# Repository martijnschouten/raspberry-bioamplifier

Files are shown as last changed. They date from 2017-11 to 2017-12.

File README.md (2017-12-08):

# Raspberry-bioamplifier
This repository contains the source of a bioamplifier based on a Raspberry Pi Zero w that streams data to matlab. The project was made at the NIFTy group at the University of Twente as a demonstrator for the IEEE student measurement challange at the IEEE conference in Glasgow in 2017. 

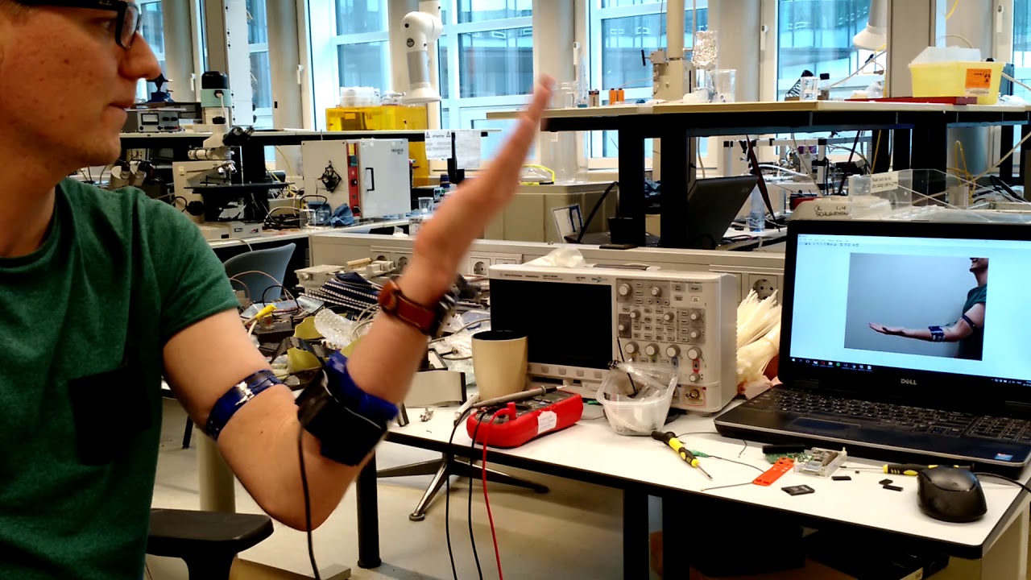
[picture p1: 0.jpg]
Link to Youtube video (https://youtu.be/Y4tf-qSCpeE "Video on Youtube")


(Click image to play video)

To be able to measure the EMG and FMG a bioamplifier shield for the raspberry pi zero w is develloped. The schematic and the layout of the pcb can be found in the bioamplifier folder. This PCB contains an 24 bit ADC, a quad opamp for measurements and one aditional single opamp that can be used as a driven right leg. As this was a prototype, each opamp has many resistors placed around it that do not all have to be soldered. By soldering certain resistors the opamp can be configured as a FMG sensor or as an EMG sensor. The specific configuration used for the demo in Glasgow can be found in the folder "demo configuration"

The data form the adc is read out using an Raspberry Pi Zero W. The program written in c++ used to read out the ADC and send the data to matlab via TCP/IP can be found in the "raspberry code" folder. The matlab scripts used to stream and process the data on the other side can be found in the folder "matlab scripts".

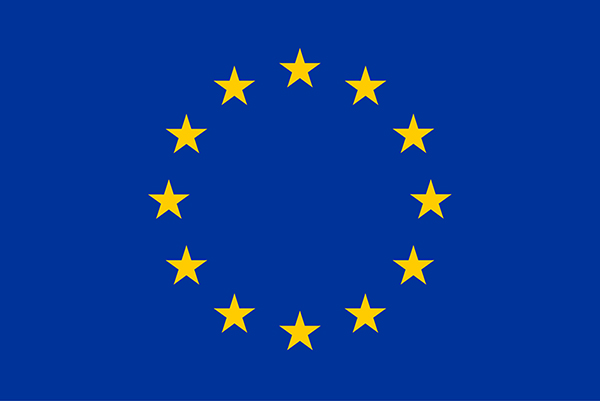
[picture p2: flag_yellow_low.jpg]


This project has received funding from the European Union’s Horizon 2020 research and innovation programme under grant agreement No. 688857 (SoftPro)

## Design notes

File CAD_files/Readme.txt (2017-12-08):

More info about cad files on: https://www.thingiverse.com/thing:2699263
The prints are made on a FlashForge Creator Pro fitted with a Flexion Extruder. The material used is NinjaFlex for the non conductive parts and PI-ETPU 85-700+ (http://palmiga.com) for the conducive parts. 

Band_ETPU.stl and Band_NinjaFlex.stl are one model, the .stl files have the same coordinate axis and can easily be combined in sliver software like simplfy3D, then assign each .stl to one material. BandCapEtpu.stl and BandCapNinjaFlex.stl are also one model.

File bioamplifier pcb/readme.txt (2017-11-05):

The PCB is designed using Kicad and it's dimensions are such that it can be ordered as a 5x5cm pcb at the big chinese PCB manufacturers.

The PCB contains an 24 bit ADC, a quad opamp for measurements and one aditional single opamp that can be used as a driven right leg. As this was a prototype, each opamp has many resistors placed around it that do not all have to be soldered. By soldering certain resistors the opamp can be configured as for example a FMG sensor or as an EMG sensor.

Bugs and options for improvement:
1. The capacitances (C6-C9) of the low pass filters in front of the ADC result in noise on the analog ground, when high capacitance values are used (1 uF).
2. Daisy chaining the boards is not possible since:
	-No external clock can supplied
	-A mix up of the CS and the DRDY signal...
3. The u.fl connectors are not very reliable, it might be a good idea to replace them mmcx connectors or a 3d printed connector
4. The resolution of the ADC is not fully used due to the large amount of noise. Further research on what is causing this noise is necessary.

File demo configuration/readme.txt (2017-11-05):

FMG:
U1C (channel 3) is configured as an transimpedance amplifier to the analog ground with an feedback resistor of 3.9 kOhm. The shielding of the u.fl connector is not used since there was a short from the shield to the core near the FMG sensor. 

U1B (channel 2) is not used, but is configured as a unity gain amplifier for debug purposes. It's u.fl connector is used to connect the general ground to FMG resistor. The general ground is 1.8 volt below the analog ground and therefore can be used to apply a voltage over the FMG resistor.

EMG:
U1A (channel 1) is used as reference channel. The measured signal is send back to the patient with a negative gain via the driven right leg. This results in feedback loop pulling this signal to zero.

U1D (channel 4) is used as a measurement channel. This amplifier contains a high pass filter in order to filter out the DC offset of the signal and therefore allow a larger gain.

Futhermore the signal and in case of channel 4 the AC part of the signal is fed back to the shield. This is done in order to reduce the input capacitance due to the capacitance of the shielded cable.

U5 is configured as an amplifier with negative feedback, such that it functions as a driven right leg. The gain of the negative amplifier is limited at high frequencies (cutoff at 16Hz).

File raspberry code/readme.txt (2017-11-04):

In order to run and compile the code:

1. copy the content of this folder to /usr/local/bin

2. give readSPI and readSPIhack the correct rights:
sudo chmod 775 /usr/local/bin/readSPI
sudo chmod 775 /usr/local/bin/readSPIhack

3. install the boost libraries
sudo apt-get install libboost-all-dev

4. install wiring pi:
sudo apt-get install wiringpi

5. enable SPI under interfacing options in the config menu accessed using:
sudo raspi-config

To make the program starts at startup add:
/bin/bash /usr/local/bin/readSPIhack.sh
to /etc/rc.local, just above the exit 0 command

To recompile use the compile.sh script
bash /usr/local/bin/compile.sh

To recompile the preheader use the compileStdafx.sh script
bash /usr/local/bin/compileStdafx.sh

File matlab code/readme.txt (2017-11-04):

The demo script contains a script that displays different pictures based on the measured EMG and FMG signal

The streamAndPlotData script can be used for debugging, it shows the signal of all channels.

The class ADS131a04 can be used to set up a connection with the raspberry.

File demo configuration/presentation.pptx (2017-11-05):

## IEEE sensors – student contest

Wifi bio AMPLifier

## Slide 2

- Voltage source
- Transimpedance amplifier
- That’s it

- Resistance measurements

- Schematic

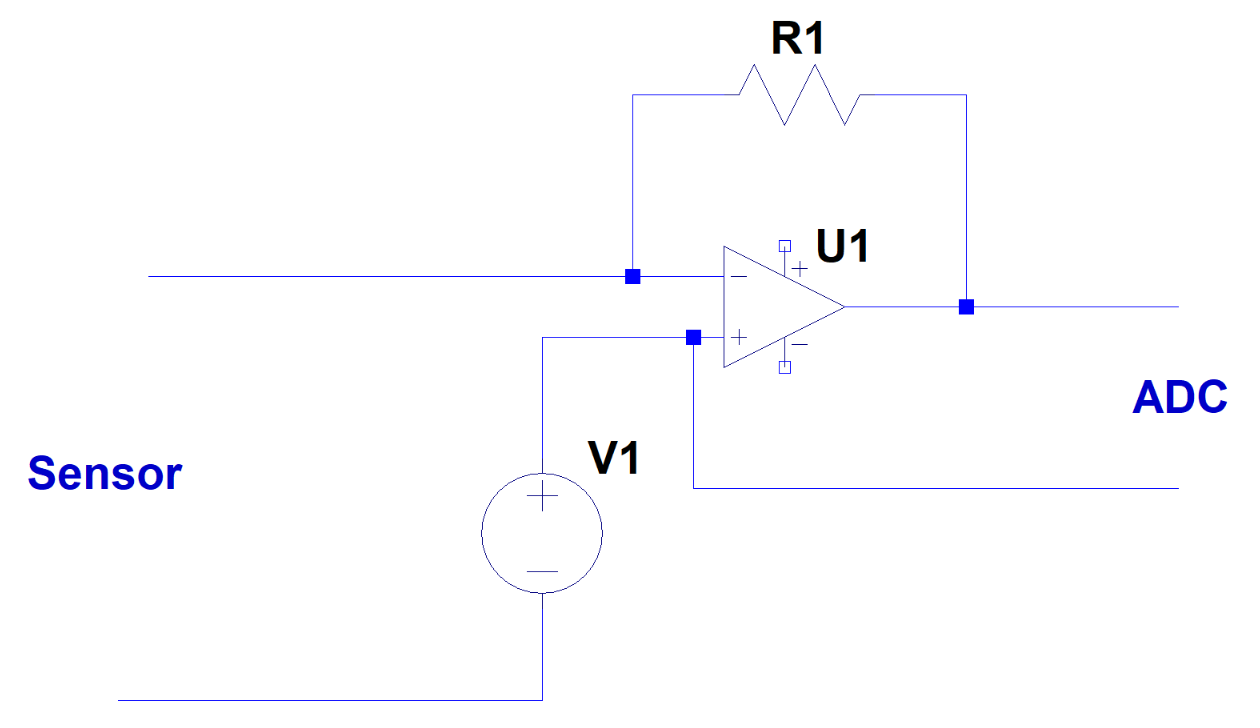
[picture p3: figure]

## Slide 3

- EMG amplifier

- Driven right leg

- Feedback loop
- Drastically reduces 50Hz noise
- Body potential ≈ ground
- When R4 is resistor
  - High frequent signals on ground
  - Cause “leaking” opamp inputs
- When R4 is capacitor
  - extra pole = instability issues

+

Non-inverting

Inverting

Body

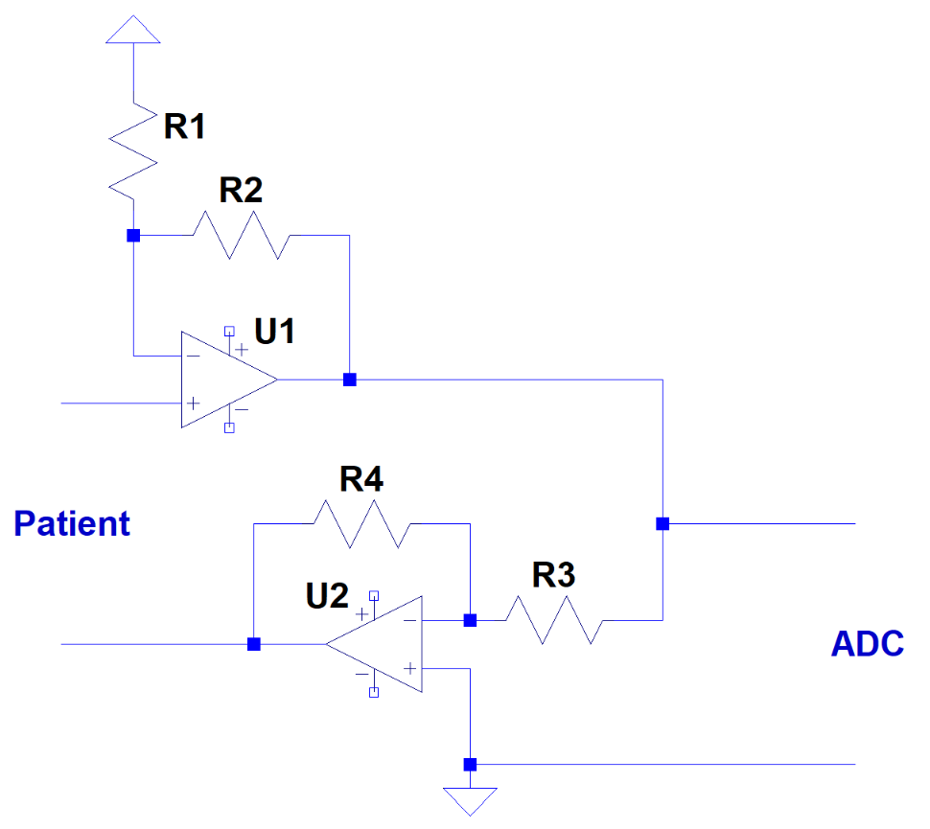
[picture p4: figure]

Non-inverting

inverting

0V

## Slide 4

- EMG amplifier

- Amplifiers

- Filters out DC
  - Allows a higher gain
- Returns applied signal on shield
  - Cancels out wire capacitance

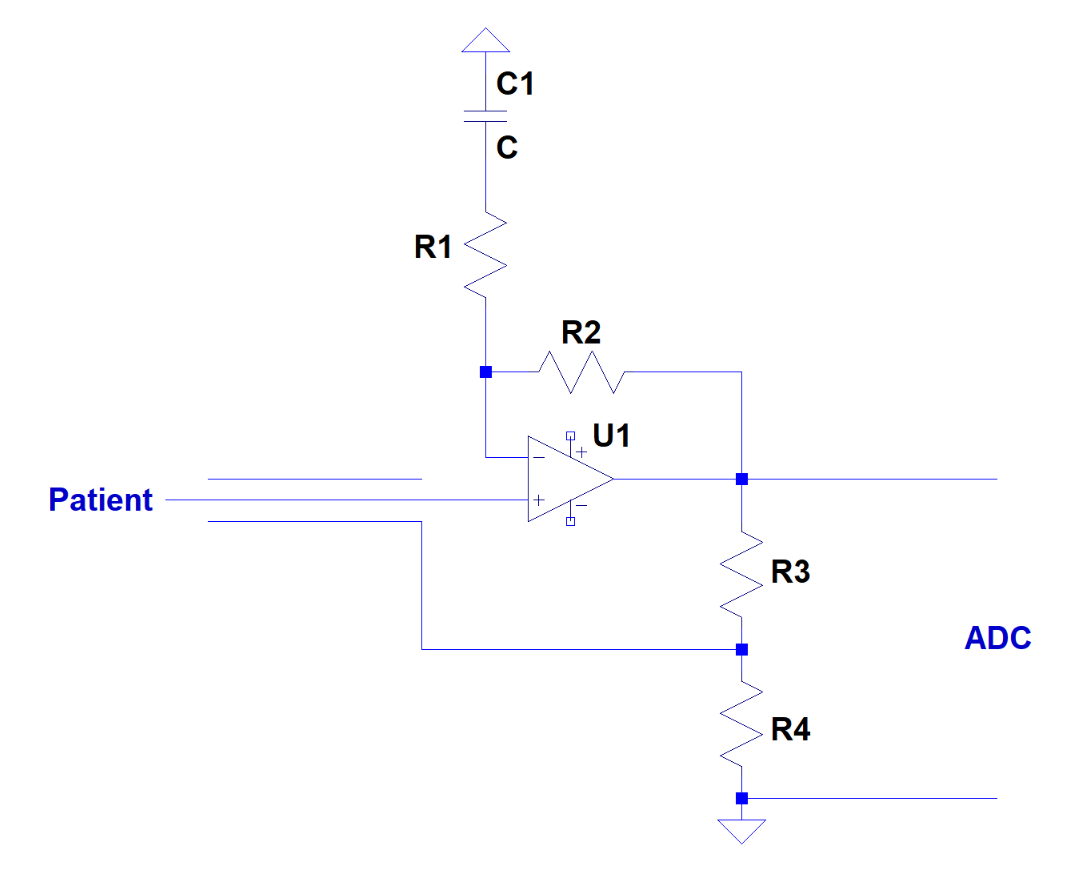
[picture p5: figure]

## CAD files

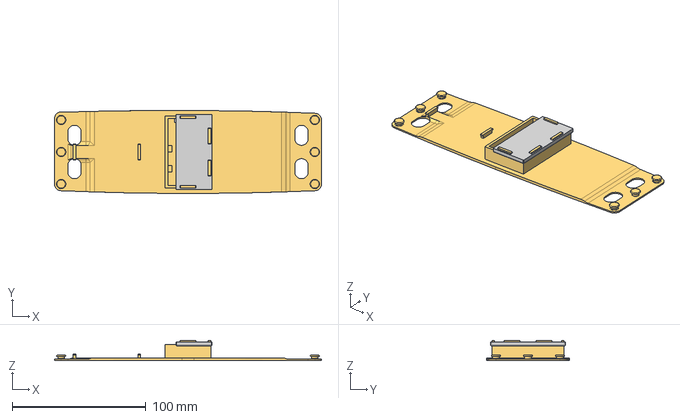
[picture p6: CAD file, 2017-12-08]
CAD_files/BandIEEE_v6.step
200.0 x 62.0 x 15.0 mm
Ninjaflex
Cap

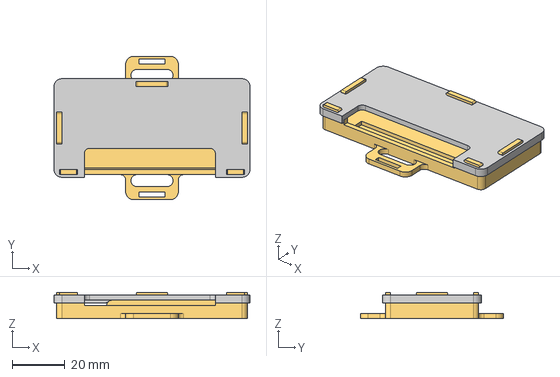
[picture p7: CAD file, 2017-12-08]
CAD_files/Pi_holder_v5.step
74.5 x 54.5 x 10.0 mm

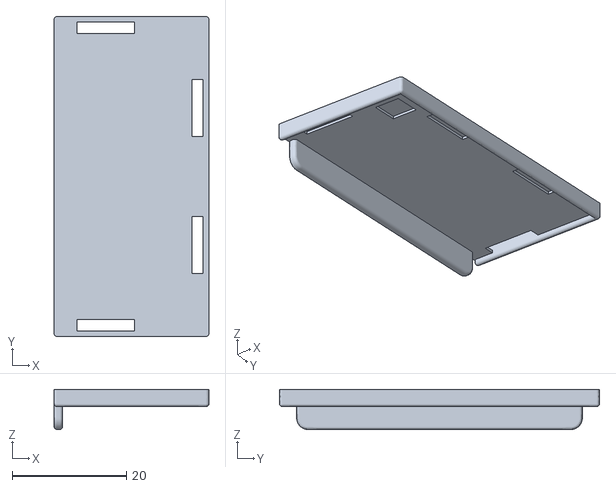
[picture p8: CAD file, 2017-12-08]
CAD_files/BandCapNinjaFlex.stl
27.1 x 56.0 x 7.00

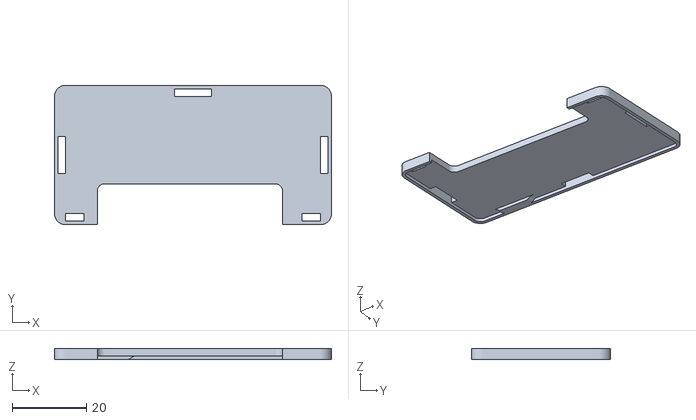
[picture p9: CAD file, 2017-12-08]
CAD_files/CapPi_holder.stl
74.5 x 37.5 x 3.00

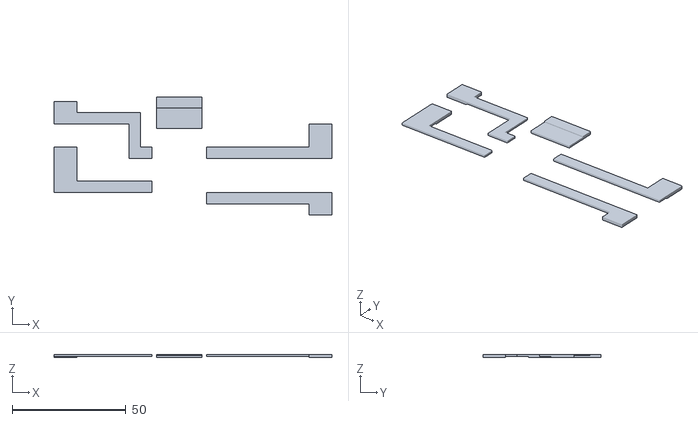
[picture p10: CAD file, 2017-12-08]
CAD_files/Band_ETPU.stl
122.0 x 52.0 x 1.50

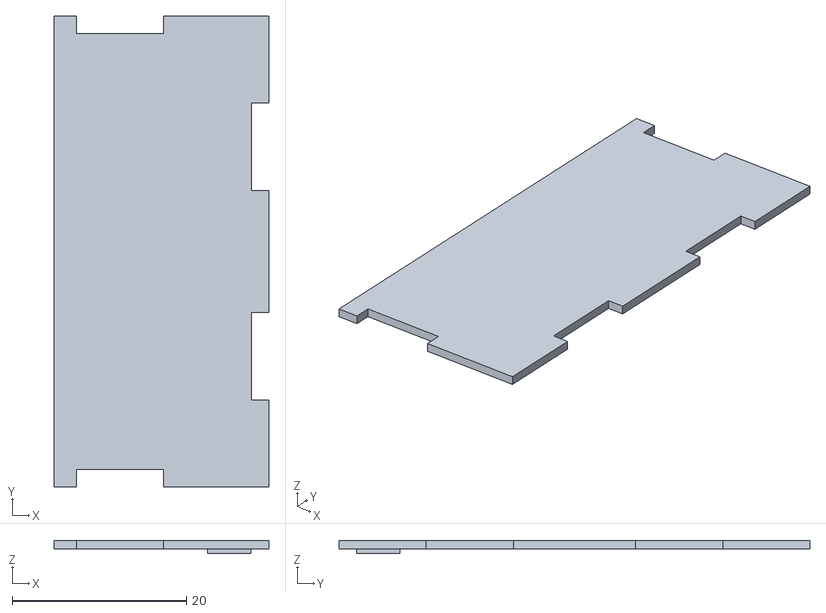
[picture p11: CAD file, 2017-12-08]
CAD_files/BandCapEtpu.stl
24.6 x 54.0 x 1.50

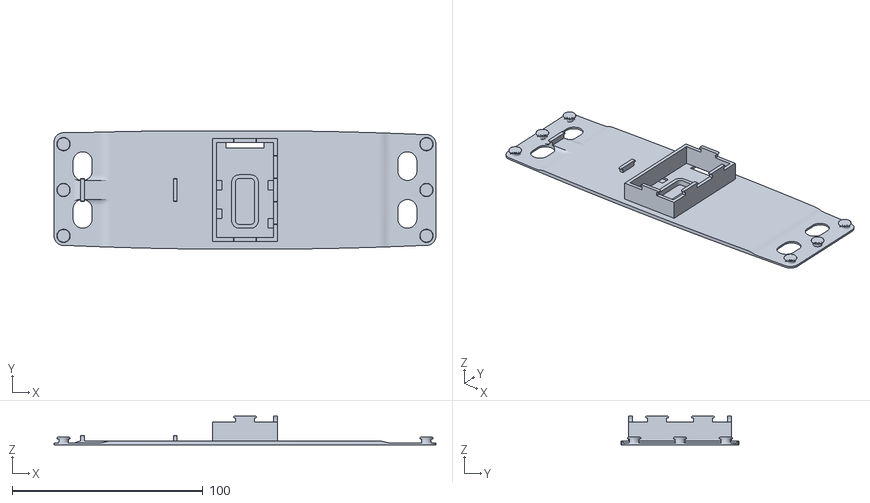
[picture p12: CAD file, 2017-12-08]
CAD_files/Band_NinjaFlex.stl
200.0 x 62.0 x 15.0

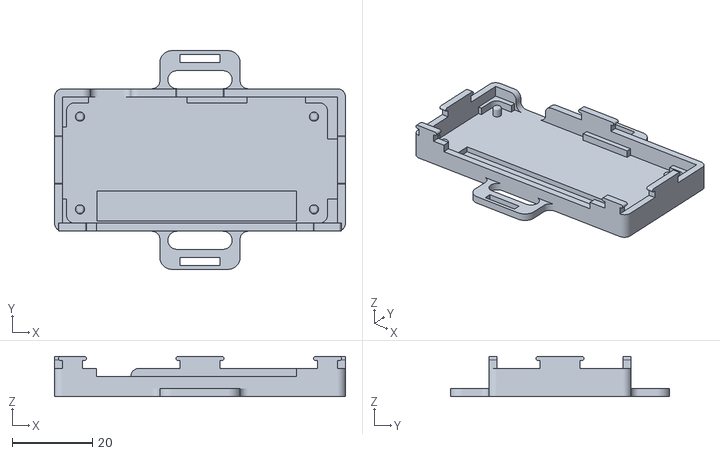
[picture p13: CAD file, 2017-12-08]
CAD_files/Pi_holder.stl
72.5 x 54.5 x 10.0

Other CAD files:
CAD_files/Pi_holder_v5.f3d

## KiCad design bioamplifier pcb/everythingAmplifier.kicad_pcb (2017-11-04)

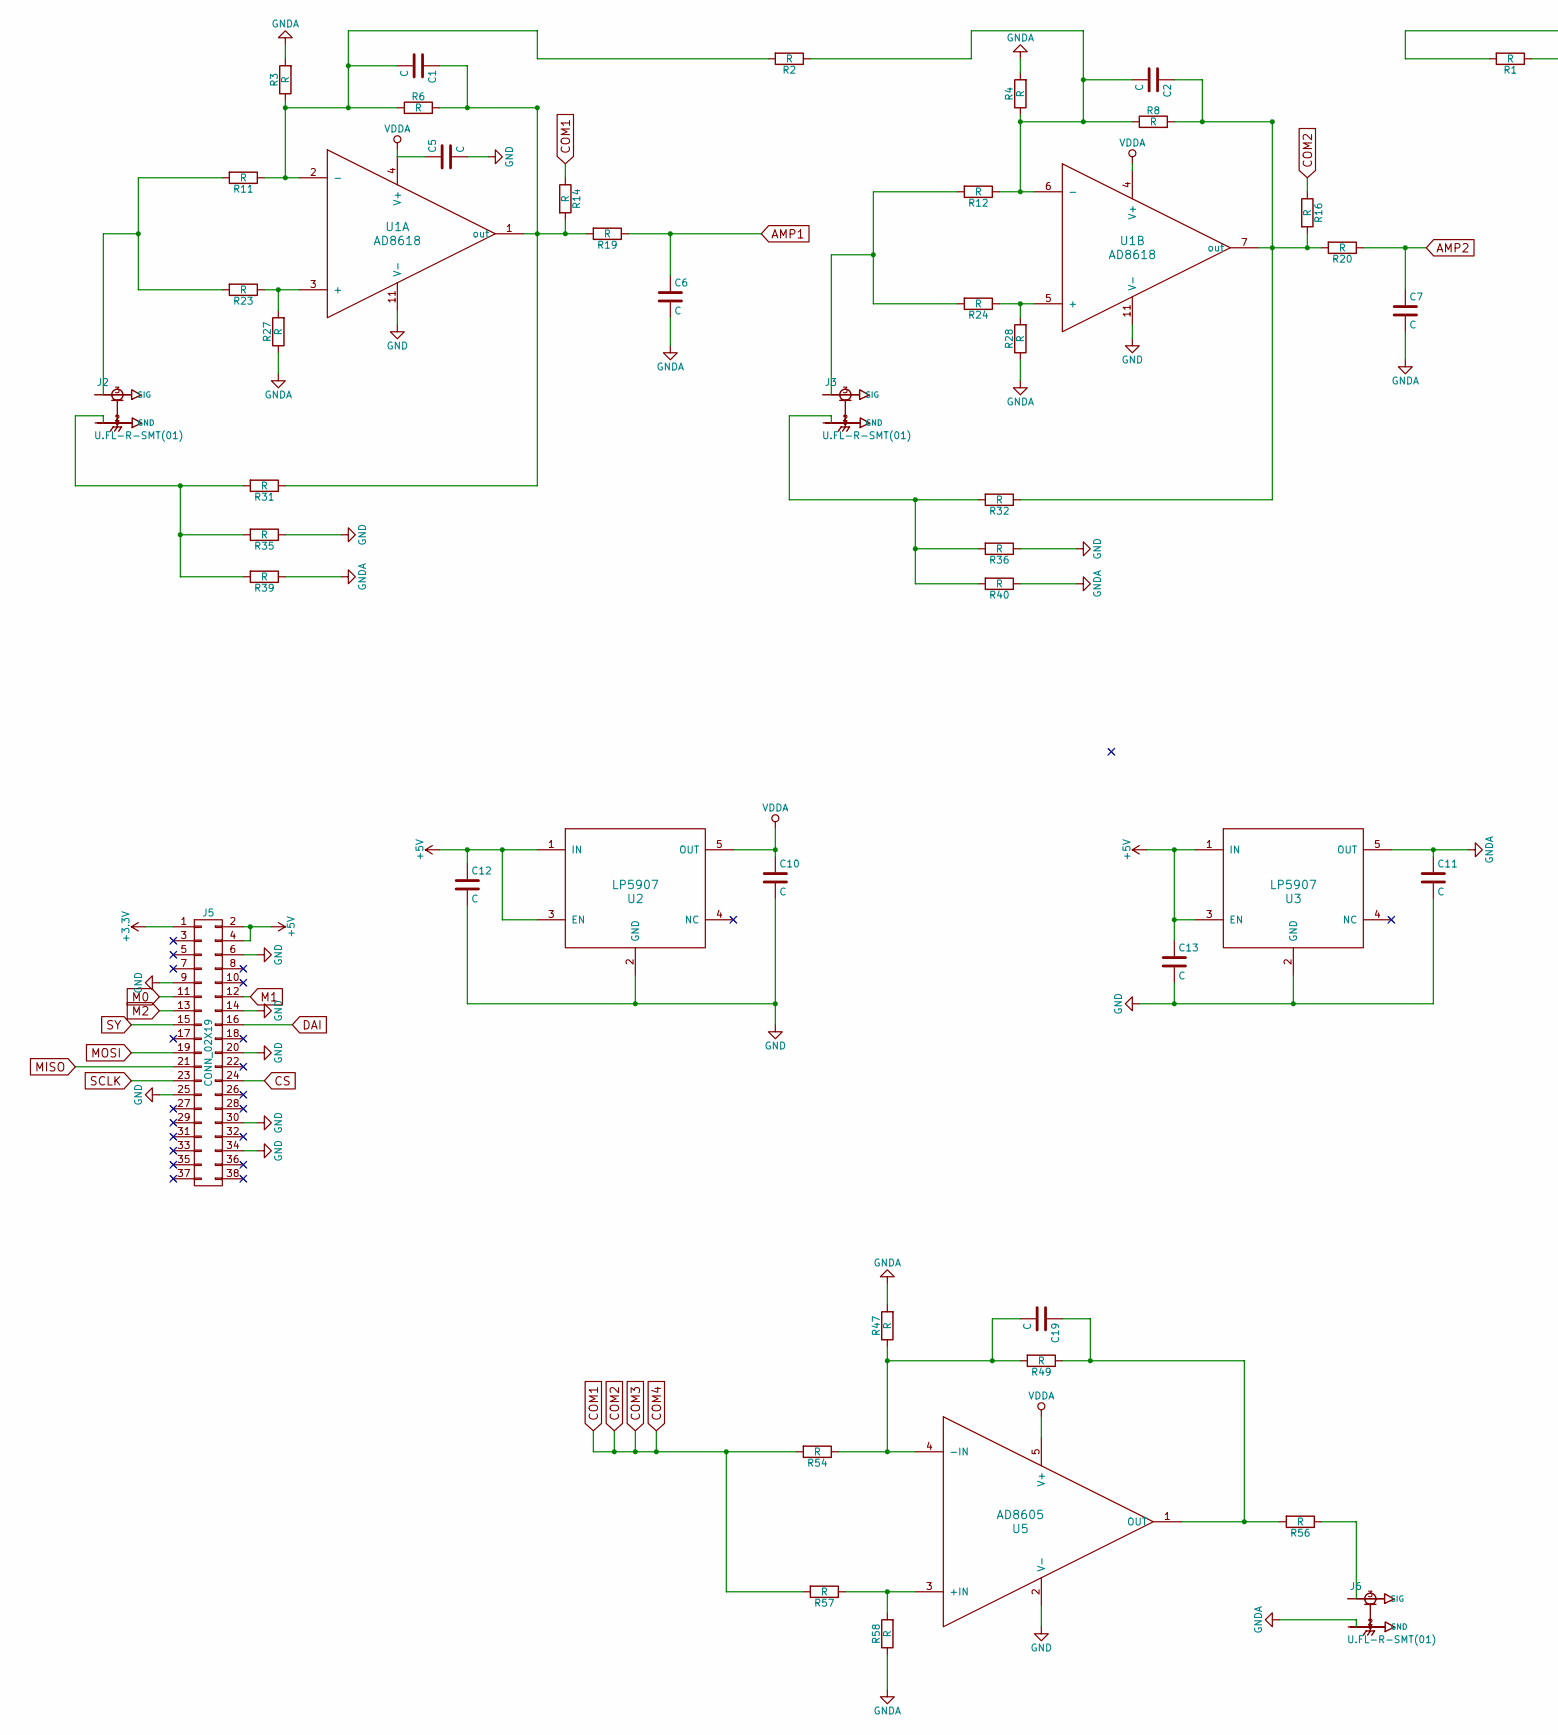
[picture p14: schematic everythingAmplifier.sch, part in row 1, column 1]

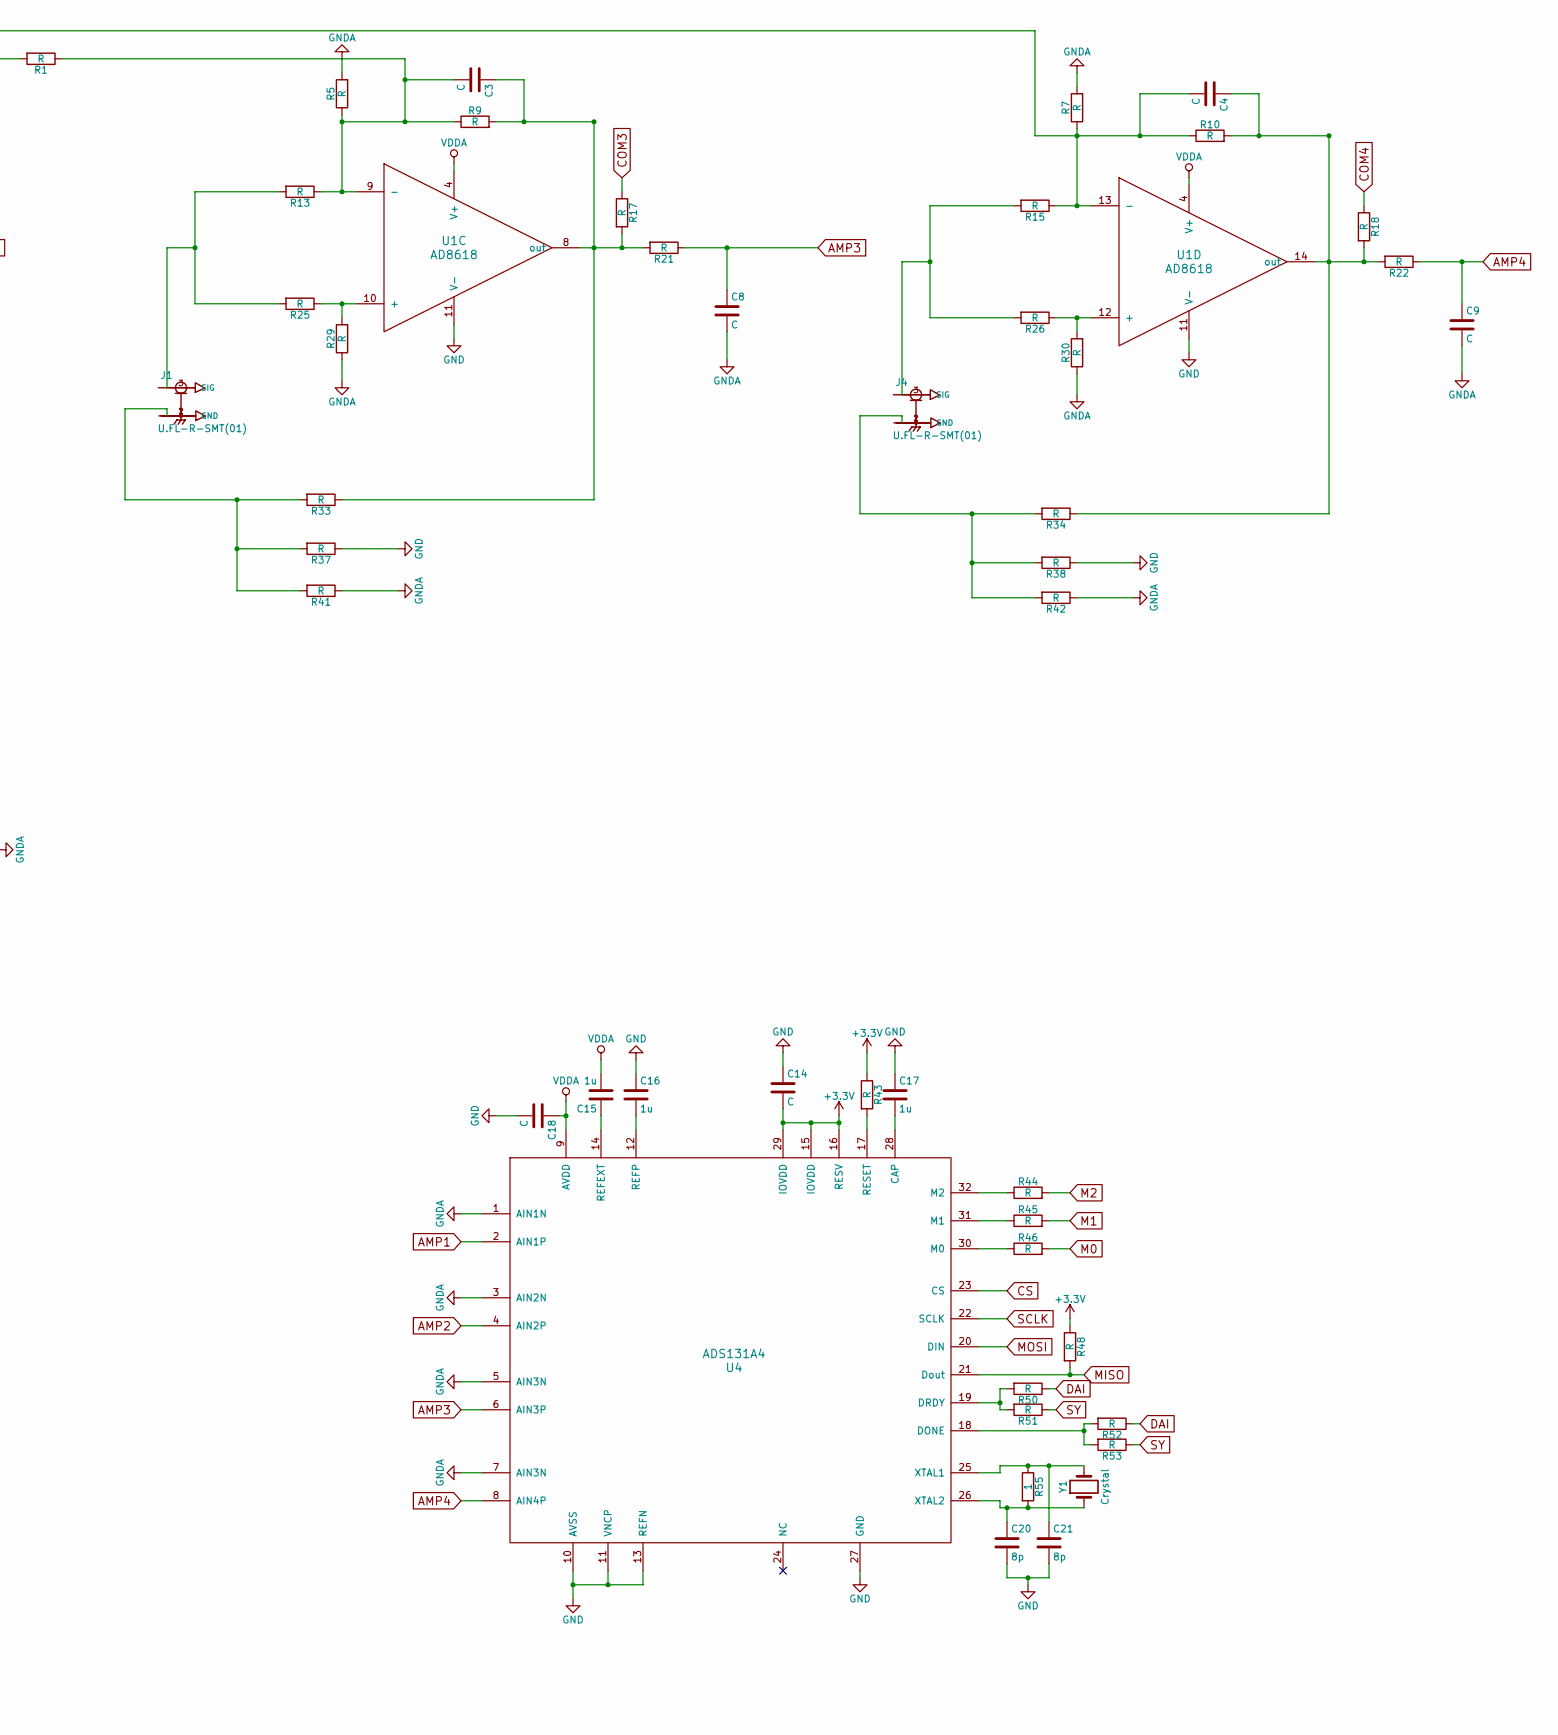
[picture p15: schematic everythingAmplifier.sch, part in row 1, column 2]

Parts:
C1, C2, C3, C4, C5, C6, C7, C8, C9, C10, C11, C12, C13, C14, C18, C19: C; C_0805_HandSoldering
C15, C16, C17: 1u; C_0805_HandSoldering
C20, C21: 8p; C_0805_HandSoldering
J1, J2, J3, J4, J6: U.FL-R-SMT(01); HRS_U.FL-R-SMT(01)
J5: CONN_02X19; Pin_Header_Straight_2x19_Pitch2.54mm
R1, R2, R3, R4, R5, R6, R7, R8, R9, R10, R11, R12, R13, R14, R15, R16, R17, R18, R19, R20, R21, R22, R23, R24, R25, R26, R27, R28, R29, R30, R31, R32, R33, R34, R35, R36, R37, R38, R39, R40, R41, R42, R43, R44, R45, R46, R47, R48, R49, R50, R51, R52, R53, R54, R56, R57, R58: R; R_0805_HandSoldering
R55: 1; R_0805_HandSoldering
U1: AD8618; SOIC-14_N
U2, U3: LP5907; SOT-23-5_HandSoldering
U4: ADS131A4; LQFP-32_5x5mm_Pitch0.5mm
U5: AD8605; SOT-23-5_HandSoldering
Y1: Crystal; Crystal_HC49-4H_Vertical

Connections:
+3V3: C14.2, J5.1, R43.1, R48.1, U4.15 (IOVDD), U4.16 (RESV), U4.29 (IOVDD)
+5V: C12.1, C13.1, J5.2, J5.4, U2.1 (IN), U2.3 (EN), U3.1 (IN), U3.3 (EN)
AMP1: C6.1, R19.1, U4.2 (AIN1P)
AMP2: C7.1, R20.1, U4.4 (AIN2P)
AMP3: C8.1, R21.1, U4.6 (AIN3P)
AMP4: C9.1, R22.1, U4.8 (AIN4P)
COM1: R14.1, R16.1, R17.1, R18.1, R54.2, R57.2
CS: J5.24, U4.23 (CS)
DAI: J5.16, R50.1, R52.1
GND: C5.2, C10.2, C11.2, C12.2, C13.2, C14.1, C16.1, C17.1, C18.2, C20.2, C21.2, J5.6, J5.9, J5.14, J5.20, J5.25, J5.30, J5.34, R35.1, R36.1, R37.1, R38.1, U1.11 (V-), U2.2 (GND), U3.2 (GND), U4.10 (AVSS), U4.11 (VNCP), U4.13 (REFN), U4.27 (GND), U5.2 (V-)
M0: J5.11, R46.2
M1: J5.12, R45.2
M2: J5.13, R44.2
MISO: J5.21, R48.2, U4.21 (Dout)
MOSI: J5.19, U4.20 (DIN)
unnamed: C1.1, R6.2, R14.2, R19.2, R31.1, U1.1 (out)
unnamed: C1.2, R2.2, R3.1, R6.1, R11.1, U1.2 (-)
unnamed: C2.1, R8.2, R16.2, R20.2, R32.1, U1.7 (out)
unnamed: C2.2, R2.1, R4.1, R8.1, R12.1, U1.6 (-)
unnamed: C3.1, R9.2, R17.2, R21.2, R33.1, U1.8 (out)
unnamed: C4.1, R10.2, R18.2, R22.2, R34.1, U1.14 (out)
unnamed: C4.2, R1.2, R7.1, R10.1, R15.1, U1.13 (-)
unnamed: C15.1, U4.14 (REFEXT)
unnamed: C16.2, U4.12 (REFP)
unnamed: C17.2, U4.28 (CAP)
unnamed: C19.1, R49.1, R56.2, U5.1 (OUT)
unnamed: C19.2, R47.1, R49.2, R54.1, U5.4 (-IN)
unnamed: C20.1, R55.2, U4.26 (XTAL2), Y1.1
unnamed: C21.1, R55.1, U4.25 (XTAL1), Y1.2
unnamed: J1.1 (GND), J1.2 (GND), R33.2, R37.2, R41.2
unnamed: J1.3 (SIG), R13.2, R25.2
unnamed: J2.1 (GND), J2.2 (GND), R31.2, R35.2, R39.2
unnamed: J2.3 (SIG), R11.2, R23.2
unnamed: J3.1 (GND), J3.2 (GND), R32.2, R36.2, R40.2
unnamed: J3.3 (SIG), R12.2, R24.2
unnamed: J4.1 (GND), J4.2 (GND), R34.2, R38.2, R42.2
unnamed: J4.3 (SIG), R15.2, R26.2
unnamed: J6.3 (SIG), R56.1
unnamed: R23.1, R27.2, U1.3 (+)
unnamed: R24.1, R28.2, U1.5 (+)
unnamed: R25.1, R29.2, U1.10 (+)
unnamed: R26.1, R30.2, U1.12 (+)
unnamed: R43.2, U4.17 (RESET)
unnamed: R44.1, U4.32 (M2)
unnamed: R45.1, U4.31 (M1)
unnamed: R46.1, U4.30 (M0)
unnamed: R50.2, R51.2, U4.19 (DRDY)
unnamed: R52.2, R53.2, U4.18 (DONE)
unnamed: R57.1, R58.2, U5.3 (+IN)
SCLK: J5.23, U4.22 (SCLK)
SY: J5.15, R51.1, R53.1
VDDA: C5.1, C10.1, C15.2, C18.1, U1.4 (V+), U2.5 (OUT), U4.9 (AVDD), U5.5 (V+)

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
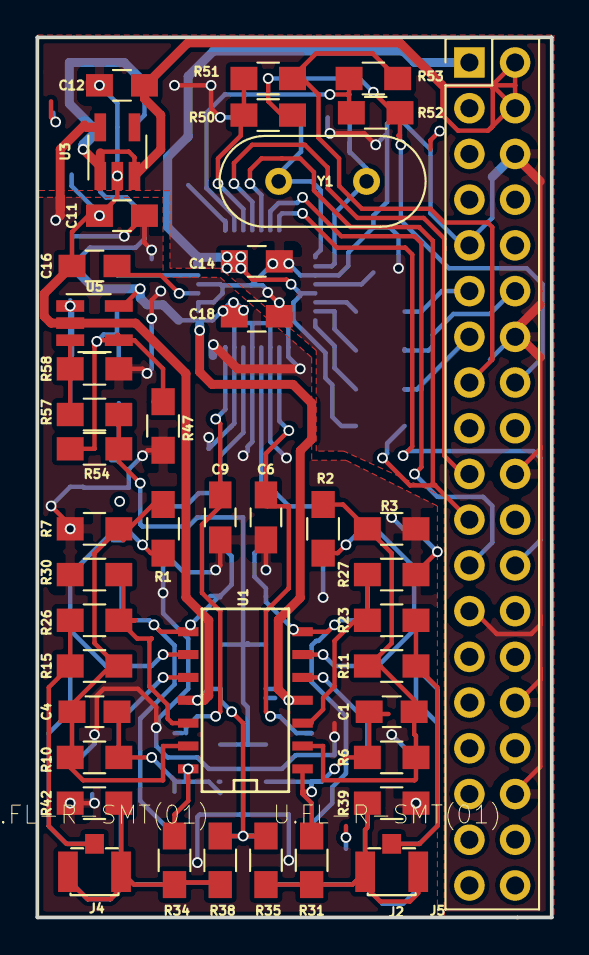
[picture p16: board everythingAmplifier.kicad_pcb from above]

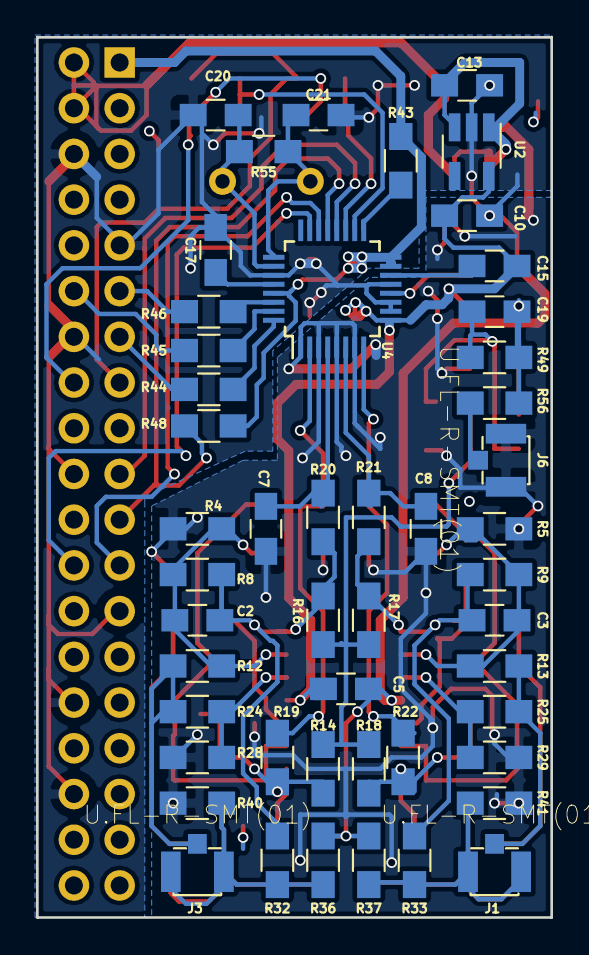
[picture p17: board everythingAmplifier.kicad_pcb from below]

Board: 2 copper layers, 28.6 x 48.9 mm, 91 parts (49 on the bottom side), 54 nets.

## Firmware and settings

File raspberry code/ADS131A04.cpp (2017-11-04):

#include "stdafx.h"
#include "ADS131A04.h"
#include <wiringPi.h>
#include <chrono>
#include <iostream>
#include <sstream>


unsigned char ADS131A04::frameSize = 3;
unsigned char * ADS131A04::buffer = new unsigned char[30];
boost::circular_buffer<uint8_t> ADS131A04::data(BUFFERSIZE*CHANNELS*3);
boost::circular_buffer<uint64_t> ADS131A04::timeStamps(BUFFERSIZE);

ADS131A04::ADS131A04(void){
}

void ADS131A04::init(){
	int result;
	wiringPiSetup();
	
	pinMode(0,OUTPUT);
	pinMode(1,OUTPUT);
	pinMode(2,OUTPUT);
	pinMode(5,OUTPUT);
	digitalWrite(0,HIGH);
	digitalWrite(1,LOW);
	digitalWrite(2,LOW);
	delay(1);
	//reset in order to clock in 0,1 and 2
	digitalWrite(5,LOW);
	delay(1);
	digitalWrite(5,HIGH);

	//init spi and data ready interupt
	result = wiringPiSPISetupMode(0,1000000,1);

	
	//unlock device
	buffer[0] = 0x06;
	buffer[1] = 0x55;
	buffer[2] = 0x00;
	writeAndCheck();
	
	//reset device
	buffer[0] = 0x00;
	buffer[1] = 0x11;
	buffer[2] = 0x00;
	wiringPiSPIDataRW(0,buffer,frameSize);
	delay(10);

	 //unlock device
	buffer[0] = 0x06;
	buffer[1] = 0x55;
	buffer[2] = 0x00;
	writeAndCheck();

	unsigned char temp;
	//write CLK2 register
	temp  = (0b001 << 5); //fmod = ficlk/2
	temp |= 0x01; //fdata = fmod/1024
	writeRegister(0x0E,temp);

	//write CLK1 register
	temp  = (0b0<<7);//use XTAL1/CLKIN
	temp |= (0b001<<1); // ficlk = fclkin/2
	writeRegister(0x0D,temp);

	//write A_SYS_CFG
	writeRegister(0x0B,0b01111000);//enable 4V  internal reference
	
	//write ADC_ENA
	writeRegister(0x0F,0x0F);//enable all ADC's
	wiringPiSPIDataRW(0,buffer,frameSize);


	//wake up
	buffer[0] = 0x00;
	buffer[1] = 0x33;
	buffer[2] = 0x00;
	writeAndCheck();
	frameSize = 3*5;
	
	result = wiringPiISR(4,INT_EDGE_FALLING,&ADS131A04::dataReady);
	//std::cout << "ISR init result:" << result << std::endl;
}


void ADS131A04::dataReady(void){
	//read out a register
	//check if F_SPI error flag is set
	bool error = FALSE;
	if (buffer[1] == 32) error = TRUE;
		for( int i = 0; i<frameSize;i++)buffer[i] = 0;
	//if there is an F_SPI error flag, reset error flag
	if(error){
		buffer[0] =  (0b001 <<5);
		buffer[0] |= (0x05);
		buffer[1] = 0x00;
		buffer[2] = 0x00;
		error = TRUE;
	}
	//reset error flag and read out data
	wiringPiSPIDataRW(0,buffer,frameSize);
	//request current time
	timeStamps.push_back(std::chrono::duration_cast<std::chrono::microseconds>(std::chrono::system_clock::now().time_since_epoch()).count());
	
	//store data in the cyclic buffer
	for(int i1 = 0; i1<CHANNELS;i1++){
		for(int i2 = 0;i2<3;i2++){
			data.push_back(buffer[(i1+1)*3+i2]);
		}
	}
}

//old inefficient function that returns the data as a fixed point float converted to text
std::string ADS131A04::getDataString(void){
	int dataPoints = timeStamps.size()-1;
	char datastring[dataPoints*100];
	//std::cout << "datapoints: " << dataPoints << '\n';
	int i2 = 0;
	for(int i1 = 0; i1<dataPoints;i1++){
		i2 += sprintf(&datastring[i2],"%i",timeStamps.front()/(uint64_t)60000000);
		datastring[i2] = ';';
		i2++;
		i2 += sprintf(&datastring[i2],"%i",timeStamps.front()%(uint64_t)60000000);
		timeStamps.pop_front();
		for(int i3 = 0; i3 < CHANNELS; i3++){
			datastring[i2] = ';';
			i2++;
			
			uint32_t temp1 = 0;
			temp1 += (data.front()<<16);
			data.pop_front();
			temp1 += (data.front()<<8);
			data.pop_front();
			temp1 += data.front();
			data.pop_front();
			temp1 = temp1<<8;
			int32_t temp2 = (int32_t)temp1;
			double temp3 = 4.768371582e-7*temp2/256;
			i2 += sprintf(&datastring[i2],"%1.6f",temp3);
		}
		i2 += sprintf(&datastring[i2],"\n");
	}
	std::string dataString2(datastring);
	//std::cout << "new batch\n";
	//std::cout << dataString2;
	return dataString2;
}
		

//more efficient way of reading out data, using the values of 128-255 of a char to store the data.
std::string ADS131A04::getDataBinary(void){
	int dataPoints = timeStamps.size()-1;
	
	if (dataPoints > 0){
		unsigned char datastring[dataPoints*30];
		int i2 = 0;
		
		for(int i1 = 0; i1<dataPoints;i1++){
			uint32_t min = timeStamps.front()/(uint64_t)60000000;
			uint32_t us = timeStamps.front()%(uint64_t)60000000;
			timeStamps.pop_front();
			for(int i3 = 3;i3>=0;i3--){
				datastring[i2] = 128+((min & (0x7F << (i3*7)))>>(i3*7));
				i2++;
			}
			datastring[i2] = ';';
			i2++;
			for(int i3 = 3;i3>=0;i3--){
				datastring[i2] = 128+((us & (0x7F << (i3*7)))>>(i3*7));
				i2++;
			}
			for(int i3 = 0; i3 < CHANNELS; i3++){
				datastring[i2] = ';';
				i2++;
				datastring[i2] = 128+((data.front() & 0xFE)>>1);
				i2++;
				datastring[i2] = 128+((data.front() & 0x1) << 6);
				data.pop_front();
				datastring[i2] = datastring[i2] + ((data.front() & 0xFC) >> 2);
				i2++;
				datastring[i2] = 128+((data.front() & 0x3) << 5);
				data.pop_front();
				datastring[i2] = datastring[i2] + ((data.front() & 0xF8) >> 3);
				data.pop_front();
				i2++;
			}
			datastring[i2] = 10;
			i2++;
		}
		datastring[i2] = 0;
		std::string dataString2(reinterpret_cast<char*>(datastring));
		return dataString2;
	}
	else{
		std::string empty;
		return empty;
	}
}

void ADS131A04::writeAndCheck(void){
	//write data to a register in the ADC and check it by reading out the same register
	bool notGood = TRUE;
	unsigned char data[frameSize];
	memcpy(data, buffer,frameSize);
	printBuffer();
	while(notGood){
		memcpy(buffer,data,frameSize);
		//printBuffer();
		wiringPiSPIDataRW(0,buffer,frameSize);
		for(int i = 0; i<frameSize;i++){
			buffer[i] = 0;
		}
		wiringPiSPIDataRW(0,buffer,frameSize);
		printBuffer();
		if (buffer[1]==data[1]){
			notGood = FALSE;
			//cout << "good" << endl;
		}
	}
	printBuffer();
}

void ADS131A04::writeRegister(unsigned char address, unsigned char value){
	//write data to a register in the adc
	buffer[0] = (0b010 << 5);
	address &= 0b00011111;
	buffer[0] |= address;
	buffer[1] = value;
	buffer[2] = 0;
	writeAndCheck();
}

void ADS131A04::printBuffer(void){
	//print the buffer containing the last read data
	for(int i = 0; i < frameSize;i++){
		std::string s = std::to_string(buffer[i]);
		std::cout << s  << ';';
	}
	std::cout << std::endl;
}

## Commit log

2017-11-04 added all files
    added all files
    [everythingAmplifier-B.Cu.gbl, everythingAmplifier-B.Mask.gbs, everythingAmplifier-B.Paste.gbp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]
2017-11-04 edited pcb readme
    added driven right leg description
2017-11-04 eddited pcb description
    changed name of known bugs such that it appears on github
    added describtion
